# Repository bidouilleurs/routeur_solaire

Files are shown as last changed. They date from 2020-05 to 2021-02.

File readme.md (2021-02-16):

# Réseautonome - Routeur offgrid

## Sommaire
* [Tutoriels videos](#Tutoriels-videos)
* [Parametrage](#Parametrage)
  * [Parametrage pour l algorithme](#Parametrage-pour-l-algorithme)
  * [Fonctionnalites optionnelles du systeme](#Fonctionnalites-optionnelles-du-systeme)
  * [Parametrage le fonctionnement du serveur web](#Parametrage-le-fonctionnement-du-serveur-web)
  * [Parametrage pour le fonctionnement MQTT](#Parametrage-pour-le-fonctionnement-MQTT)
* [Flash sur ESP](#Flash-sur-ESP)
  * [PlatformIO filaire](#PlatformIO-filaire)
  * [PlatformIO OTA](#PlatformIO-OTA)
* [Developpement](#Developpement)

## Tutoriels videos

Fonctionnement

(https://www.youtube.com/watch?v=k4qtnl1ytJM)

Présentation du prototype

(https://www.youtube.com/watch?v=r0o6uWTO2Bw)

Démonstration

(https://www.youtube.com/watch?v=PUMbBfnpi2k)

Envoyer le programme sur l'esp

(https://www.youtube.com/watch?v=kEmMACQ-4ag)

Présentation du serveur web

(https://www.youtube.com/watch?v=cQqW8xrT0VU)

Explication Hardware

(https://www.youtube.com/watch?v=aPKQgpmWH7U)

Assemblage partiel Hardware

(https://www.youtube.com/watch?v=y1rwfJ6BLlo)

Explication de corrections mineures

(https://www.youtube.com/watch?v=yLEv1khMI3Y)

## Parametrage
### Parametrage pour l algorithme
| Champs | Fichier | default |  description |
| --- | :---: |---: |---:|
| zeropince  | settings.h | -100 | valeur mesurer à zéro |
| coeffPince  | settings.h |  0.0294 | Calculer le coefficient |
| coeffTension  | settings.h | 0.0177533 | diviseur de tension |
| seuilDemarrageBatterie  | settings.h | 56 | seuil de mise en marche de la regulation dans le ballon |
| toleranceNegative  | settings.h | 0.5 | autorisation de 500mA négative au moment de la charge complète |
| utilisation2Sorties  | settings.h | false | validation de la sortie 2eme gradateur |
| temperatureBasculementSortie2  | settings.h | 60 | température pour démarrer la regul sur la sortie 2 |
| temperatureRetourSortie1  | settings.h | 45 |température pour rebasculer sur le premier gradateur  |
| relaisStatique  | settings.h | false | Indique si un relais statique est utilisé |
| seuilMarche  | settings.h | 50 | température ou tension de déclenchement du relais |
| seuilArret  | settings.h | 45 | température ou tension d'arret du relais |
| tensionOuTemperature  | settings.h | "V" | Indique si le seuil est en "V"olts ou en "D"egrés|
| correctionTemperature  | settings.h | -2.3 | |
| basculementMode  | settings.h | "T" |  Choix du mode de basculement : T->température, P-> Puissance zero|
| actif  | settings.h | true | permet d'activer ou désactiver le système
| utilisationPinceAC  | settings.h | true | Utilisation d'une Pince pour la mesure AC
| seuilCoupureAC  | settings.h | 0.3 | Seuil de coupure pour la pince AC
| coeffMesureAc  | settings.h | 0.321 | Coeff de mesure de la pince AC

### Fonctionnalites optionnelles du systeme
Les champs décrits ci-dessous permettent d'activer/désactiver certaines options
Ils sont présent dans le fichier settings.h. Si l'option ne vous interesse pas, il faut mettre la ligne en commentaire (commencer la ligne par '//')
Pour activer l'option :
```
#define  EcranOled 
```
Pour **ne pas** activer l'option
```
//#define  EcranOled 
```

| Champs | Description |
| --- | ---: |
| parametrage | A **n**'utiliser **que** pour faire les essais sans les accessoires  |
| MesureTemperature | Permet la lecture de la sonde de dallas température  |
| Pzem04t | utilise un pzem004 pour la mesure de puissance dans le ballon  |
| Sortie2 | Indique la connexion d'un deuxième Triac  |
| WifiMqtt | Permet la connexion Mqtt sur un serveur : récupération et envoie de données pour de la supervision  |
| Ecran_inverse | Permet d'inverser l'écran
| WifiServer | Met à disposition une page web pour visualiser les données du systèmes et modifier les valeurs de l'algorithme |
| EcranOled | Affichage de certaines infos sur un afficheur Oled |
| Simulation | Simulation de données pour des tests, dans le cas ou le système n'est pas branché |
| OTA | Permet la mise à jour par OTA (over the air) |

### Parametrage le fonctionnement du serveur web
Le serveur web permet de faire les régalges depuis une page web. Pour cela, Deux possibités son disponible :
* connecter l'esp au wifi domestic pour y accéder depuis un navigateur web d'un appareil connecté sur le réseau
* Mettre l'ESP en mode point d'accès (SAP) et connecter son smartphone sur le wifi de l'esp (routeur_esp32)

Dans le cas ou la connexion wifi échoue, l'ESP passe automatiquement en mode point d'accès (SAP)

| Champs | Fichier | default |  description |
| --- | :---: |---: |---:|
| ssid  | settings.h | "" |Identifiant "ssid de la  box internet |
| password  | settings.h | "" | Mot de passe de la box internet  |
| SAP  | src.ino | false | force l'ESP en point d'accès (en dehors du réseau domestique -> ssid: "routeur_esp32"; password : "adminesp32" |

### Parametrage pour le fonctionnement MQTT

Le MQTT permet de recevoir les infos de l'ESP sur un broker MQTT, et de piloter le routeur solaire.
Une connexion au wifi est obligatoire (cf. Serveur web)

| Champs | Fichier |  default |  description |
| --- | :---: |---:|---:|
| mqttServer  | settings.h | "192.168.1.28" | ip du serveur mqtt |
| mqttPort  | settings.h |  1883 | port du serveur mqtt |
| mqttUser  | settings.h |  "" | utilisateur mqtt si nécessaire |
| mqttPassword  | settings.h |  "" | mot "de passe mqtt si nécessaire |
| mqttopic  | settings.h | "sensor/solar"  | Récupération Intensite-Tension-Gradateur-Temperature-puissanceMono-rssi |
| mqttopicInput  | settings.h |  "output/solar" | *Pilotage à distance, voir le chapitre de pilotage* |
| mqttopicParam1  | settings.h |  "param/solar1" | Récupération zeropince-coeffPince-coeffTension-seuilTension-toleranceNeg-actif|
| mqttopicParam2  | settings.h | "param/solar2" |Récupération sortie2-sortie2_tempHaut-sortie2_tempBas-temporisation-sortieActive |
| mqttopicParam3  | settings.h | "param/solar3"  | Récupération sortieRelaisTemp-sortieRelaisTens-relaisMax-relaisMin-Forcage_1h-version-seuilCoupureAC-coeffMesureAc|
| mqttopicPzem1  | settings.h |  "sensor/Pzem1" | Récupération pzem infos : Intensite-Tension-Puissance-Energie-Cosf|

Pour piloter l'ESP à distance, il est possible d'envoyer des infos via mqt, sur le topic défini via la variable **mqttopicInput** (par défaut = output/solar)
| message | description |
| --- | ---:|
| rst  |  reboot l'esp
| batX  |  Changement du seuil de démarrage batterie par la valeur X (X est un nombre, ex: bat51)
| negX  |  Changement de la tolérance négative par la valeur X (X est un nombre, ex: neg0.6)
| sthX  |  Changement du seuil de température haute par la valeur X (X est un nombre, ex: sth51)
| stbX  |  Changement du seuil de température basse par la valeur X (X est un nombre, ex: stb51)
| rthX  |  Changement du relais tension haut par la valeur X (X est un nombre, ex: rth51)
| rtbX  |  Changement du relais tension bas par la valeur X (X est un nombre, ex: rtb51)
| sorX  |  Changement de la réception de sortie pour la commande du 2eme gradateur (X=0 ou X=1)
| cmfX  |  Changement de la marche forcée - 1 pour l'activer, 0 pour l'arreter (X=0 ou X=1)
| rmfX  |  Changement du ratio de la marche force, en % (ex : rfm25)
| tmpX  |  Changement du temps de la marche forcée, en minutes (ex: tmp60)
| relX  |  Changement du relais statique X=0 pour désactiver le relais, X=1 pour activer en mode températuren, X=2 pour activer en mode tension
| tmpX  |  Temps de la marche forcée. X minutes.
| temX  |  indique que le ballon est a X degrés. Uniquement dans le cas ou la propriété MesureTemperature n'est pas activée dans le settings

Pour activer / désactiver le routeur complétement, il faut envoyer un message sur le topic **router/activation**
* 1 pour activer
* 0 pour désactiver

## Flash sur ESP

### PlatformIO filaire
#### Installation VSCodium
https://github.com/VSCodium/vscodium/releases

#### Plugin PlatformIO
Depuis vscodium : 
file -> préference -> extension, rechercher et installer platformIO IDE

#### Application
Choisissez l'environnement **env:routeur_solaire**
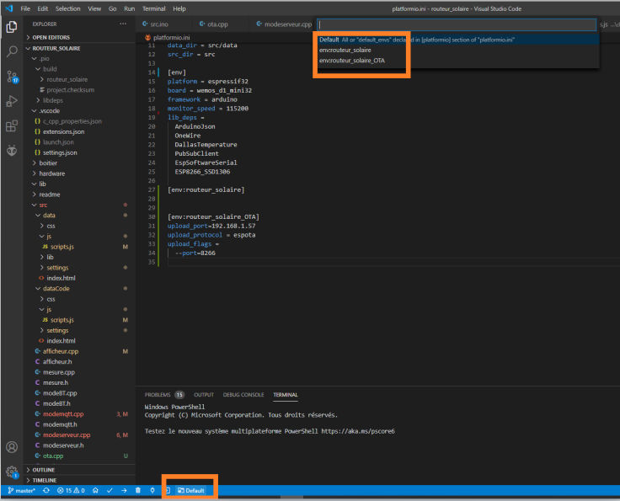
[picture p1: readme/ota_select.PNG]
Ota Select


Selectionner l'onglet plateformio dans le menu latérial (la tete de fourmi), puis déplier les options de l'environnement **env:routeur_solaire**
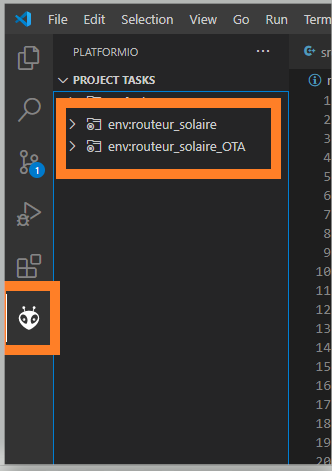
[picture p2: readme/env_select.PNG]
Env Select

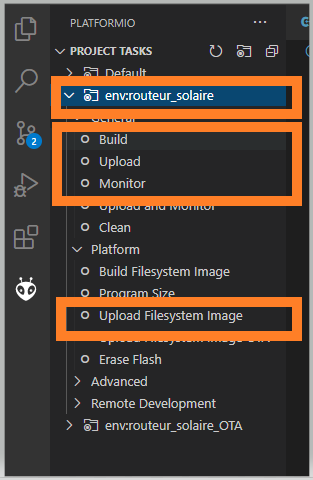
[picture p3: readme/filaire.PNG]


L'option **Build** compile le projet
L'option **upload** permet de flasher l'ESP avec le code compiler
L'option **Monitor** permet de visualiser les logs de l'ESP (infos IP, infos des mesures, ...)
L'option **upload Filesystem Image** permet d'envoyer les fichiers du serveur web

### PlatformIO OTA
**/!\\ Une première installation filaire est nécessaire !**
La mise à jour à distance nécessite que l'ESP soit connecté au réseau.

Dans le fichier plateformio.ini présent à la racine du dossier, il faut renseigner l'adresse IP de l'esp :
```
upload_port=192.168.1.57
```
L'adresse IP de l'ESP est affichée dans les logs, au démarrage de l'ESP (CF section Monitor)
IP OTA

Cliquer sur **Default** puis choisissez **env:routeur_solaire_OTA**
Ota Select

Selectionner l'onglet plateformio dans le menu latérial (la tete de fourmi), puis déplier les options de l'environnement **env:routeur_solaire_OTA**
Env Select
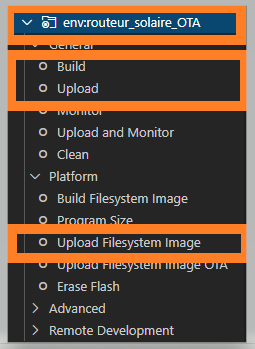
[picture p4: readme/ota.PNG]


Seul les options Build, upload et upload filesystem image sont disponibles
L'option **Build** compile le projet
L'option **upload** permet de flasher l'ESP avec le code compiler via OTA
L'option **upload Filesystem Image** permet d'envoyer les fichiers du serveur web via OTA

## Developpement
Pour changer des fonctionnalités, vous pouvez éditer le code.
Si vous souhaitez éditer le code du serveur web, il faut modifier les fichiers présents dans le dossier "dataCode" puis, une fois les changements effectués, minifier le code dans le dossier "data".
Outils en ligne pour minimifier le code : 
html / css / js : http://minifycode.com/javascript-minifier/
json : https://www.webtoolkitonline.com/json-minifier.html

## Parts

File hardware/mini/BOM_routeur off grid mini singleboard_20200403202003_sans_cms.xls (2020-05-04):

Designator | Quantity | LCSC Part number | Name | Footprint | Manufacturer Part | Manufacturer
P12 | 1 | C182807 | PinceDC | WJ2EDGVC-5.08-4P | EK508V-04P | Dinkle
Q2 | 1 | C9103 | BTA41-600BRG | TOP3-1 | BTA41-600BRG | STMicroelectronics
J1 | 1 | C65114 | Header-Male-2.54_2x3 | HDR-TH_6PIN-V-ROW2-COL3-MALE-PITCH2.54 | Header-Male-2.54_2x3 | BOOMELE
U7 | 1 | C209907 | HILINK 5V 1A | FP_HILINK_5V_1A | HLK-5M05 | HI-LINK
F3 | 1 | C3131 | 5x20 BLX-Atype Fuse holder XC-7 | FUSE-TH_L22.6-W9.0 | 5x20 BLX-Atype Fuse holder XC-7 | XCFuse
U1,U3 | 2 | C395958 | CONN-TH_2P-P9.50_DBT50G-9.5-2P | DBT50G-9.5-2P | DBT50G-9.5-2P | DIBO
J2,J3,J4 | 3 | C182803 | CON_TERMINAL_BLOCK_03-5MM | TERMINAL_BLOCK_3P_5 | ? | Dinkle
P9 | 1 | C128027 | VoltBAT | WJ2EDGVC-5.08-2P | PA001-2P | HIWA
U22 | 1 | C5665 | IDCSC-10 | IDCSC-10-SHAPE | IDCSC-10 | BOOMELE
ESP32_F | 2 | C30867 | ESP32 female header | HDR-TH_20PIN-V-ROW2-COL10-FEMALE-PITCH2.54 | Header-Female-2.54_2x10 | BOOMELE
ESP32_M | 2 | C124359 | ESP32 male header | HDR-TH_20PIN-V-ROW2-COL10-MALE-PITCH2.54 | Header-Male-2.54_2x10 | Ckmtw
U22_F | 1 | C8373 | IDC Connectors 2X5P RoHS | 2X5P | IDCSC-10-F | BOOMELE
JMP1 | 1 | C100114 | Jumper | SIP2 | ? | BOOMELE
FUSE1 | 1 | C142724 | Cartige Fuse 5x20 | 5x20 | 0216002.MXP | Littelfuse
HEAT1 | 1 | C35538 | Heatsink 24x10x100 | 24x10x100 | 24*10*100 Heat Sinks RoHS | XSD

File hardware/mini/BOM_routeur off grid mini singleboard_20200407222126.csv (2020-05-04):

ID | Name | Designator | Footprint | Quantity | Manufacturer Part | Manufacturer | Supplier | Supplier Part | LCSC Assembly
1 | 100nF | C5,C2,C7 | C0805 | 3 | CC0805KRX7R9BB104 | YAGEO | LCSC | C49678 | Yes
2 | MB10S_C2488 | D3 | DIO-BG-SMD_4P-L4.9-W4.0-P2.54-LS7.0-BL | 1 | MB10S | MDD | LCSC | C2488 | Yes
3 | EL357N(B)(TA)-G | U16 | OPTO-SMD-4_L4.4-W4.1-P2.54-LS7.0-TL | 1 | EL357N(B)(TA)-G | EVERLIGHT | LCSC | C6649 | Yes
4 | 1K | R8,R10,R3 | R0805 | 3 | 0805W8F1001T5E | UniOhm | LCSC | C17513 | Yes
5 | PinceDC | P12 | WJ2EDGVC-5.08-4P | 1 | EK508V-04P | Dinkle | LCSC | C182807
6 | DBT50G-9.5-2P | U1,U3 | CONN-TH_2P-P9.50_DBT50G-9.5-2P | 2 | DBT50G-9.5-2P | DIBO | LCSC | C395958
7 | 2.2K | R5 | R0805 | 1 | 0805W8F2201T5E | UniOhm | LCSC | C17520 | Yes
8 | BTA41-600BRG | Q2 | TOP3-1 | 1 | BTA41-600BRG | STMicroelectronics | LCSC | C9103
9 | 20K | R4 | R0805 | 1 | 0805W8F2002T5E | UniOhm | LCSC | C4328 | Yes
10 | AMS1117-3.3 | U2 | SOT-223-3_L6.5-W3.4-P2.30-LS7.0-BR | 1 | AMS1117-3.3 | AMS | LCSC | C6186 | Yes
11 | 330 | R16,R1 | R0805 | 2 | 0805W8F3300T5E | UniOhm | LCSC | C17630 | Yes
12 | Header-Male-2.54_2x3 | J1 | HDR-TH_6PIN-V-ROW2-COL3-MALE-PITCH2.54 | 1 | Header-Male-2.54_2x3 | BOOMELE | LCSC | C65114
13 | HILINK 5V 1A | U7 | FP_HILINK_5V_1A | 1 | HLK-5M05 | HI-LINK | LCSC | C209907
14 | 5x20 BLX-Atype Fuse holder XC-7 | F3 | FUSE-TH_L22.6-W9.0 | 1 | 5x20 BLX-Atype Fuse holder XC-7 | XCFuse | LCSC | C3131
15 | 1nF | C3,C4 | C0805 | 2 | CL21B102KBCNNNC | SAMSUNG | LCSC | C46653 | Yes
16 | KT-0603R | LED1 | LED0603-FD | 1 | KT-0603R | KENTO | LCSC | C2286 | Yes
17 | 100K | R12,R13,R14,R15,R22,R23,R24,R25,R26,R27,R28,R29,R30,R31,R32 | R1206 | 15 | 1206W4F1003T5E | UniOhm | LCSC | C17900 | Yes
18 | CON_TERMINAL_BLOCK_03-5MM | J2,J3,J4 | TERMINAL_BLOCK_3P_5 | 3 | ? |  | LCSC | C182803
19 | 4.7K | R6 | R0805 | 1 | 0805W8F4701T5E | UniOhm | LCSC | C17673 | Yes
20 | 100uF | C1,C6 | CAP-SMD_L3.5-W2.8 | 2 | TAJB107K006RNJ | AVX | LCSC | C16133 | Yes
21 | OR-MOC3021S | U15 | SOP-6_L7.1-W10.1-P2.54-BR | 1 | OR-MOC3021S | Orient | LCSC | C370899 | Yes
22 | 10K | R7,R17 | R0805 | 2 | 0805W8F1002T5E | UniOhm | LCSC | C17414 | Yes
23 | VoltBAT | P9 | WJ2EDGVC-5.08-2P | 1 | PA001-2P | HIWA | LCSC | C128027
24 | ZMM3V3 | D4,D1 | LL-34_L3.5-W1.5-RD | 2 | ZMM3V3 | SEMTECH | LCSC | C8056 | Yes
25 | 1K | R19,R2,R11,R18 | R1206 | 4 | 1206W4F1001T5E | UniOhm | LCSC | C4410 | Yes
26 | Pot 10k | VR1 | SINGLEPOT | 1
27 | ESP32S - Wemos ESP32S | U4 | ESP32-TEST | 1 | ESP32S
28 | IDCSC-10 | U22 | IDCSC-10-SHAPE | 1 | IDCSC-10 |  | LCSC | C5665

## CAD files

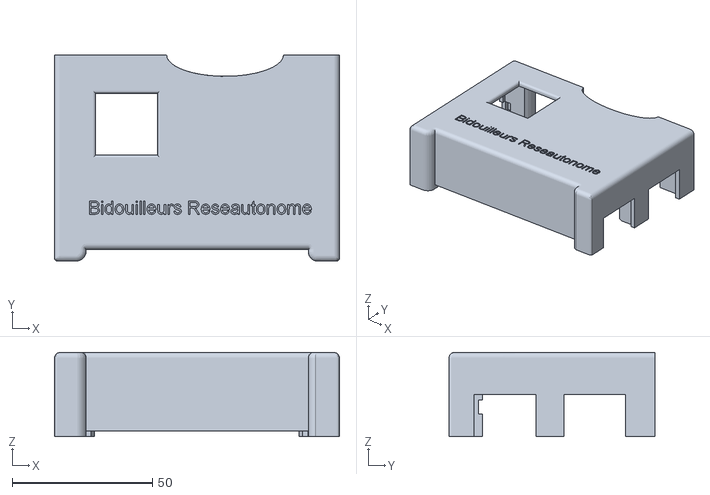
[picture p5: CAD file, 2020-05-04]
boitier/mini/routeurhaut.stl
101.6 x 73.5 x 30.0

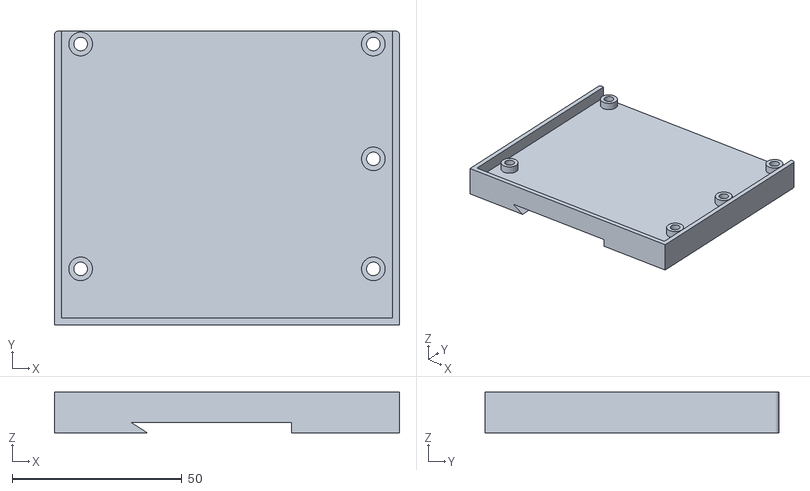
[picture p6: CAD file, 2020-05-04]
boitier/mini/routeurbas.stl
101.6 x 86.5 x 12.0

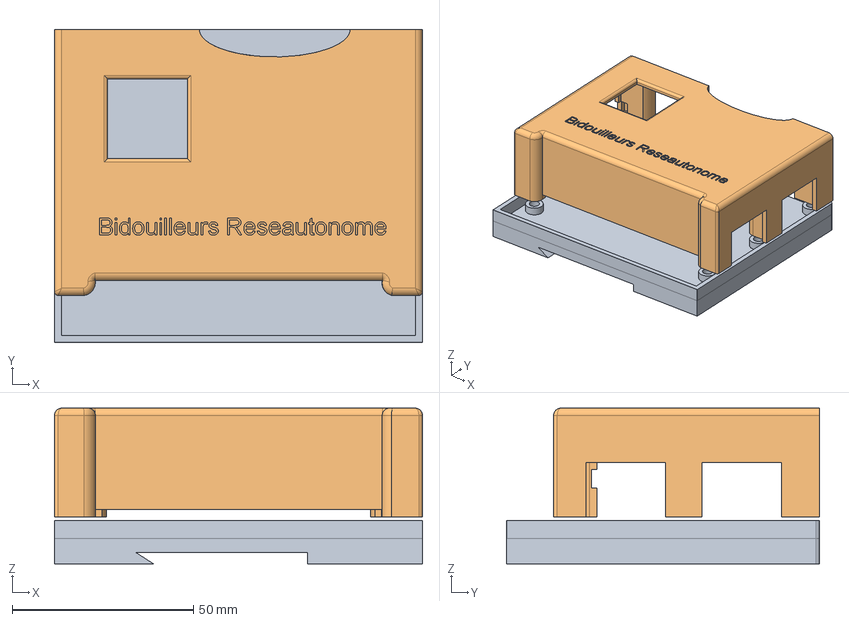
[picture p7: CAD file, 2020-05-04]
boitier/mini/routeur_fond.fcstd
101.6 x 86.5 x 43.0 mm

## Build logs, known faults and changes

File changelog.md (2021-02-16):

# Version 1.5
- Ajout d'un paramètre indiquant l'utilisation d'une pince AC, activable par le serveur web
- Possibilité de forcer le SAP depuis le serveur web
- Modification de certaines infos MQTT : ajout RSSI et mesureAC dans sensor/solar, et version-seuilCoupureAC-coeffMesureAc dans param/solar3
- Ajout du RSSI dans l'onglet communication du serveur web
- La page web indique la présence d'une nouvelle version via un message temporaire
- Meilleure gestion du passage SAP / Wifi
- Ajout d'un paramètre permettant d'inverser l'écran OLED présent dans settings.h
- Stockage des lib externes pour éviter tout problème

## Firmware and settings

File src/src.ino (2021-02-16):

//**************************************************************/
// L'équipe de bidouilleurs discord reseautonome vous présente
// la réalisation d'un gradateur pour chauffe-eau en off grid
// gradateur synchronisé sur la production photovoltaique
// sans tirage sur les batteries pour utiliser le surplus dans
// un ballon d'eau chaude
//**************************************************************/

const char *version_soft = "Version 1.5";

//**************************************************************/
// Initialisation
//**************************************************************/
#include "settings.h"
struct param routeur;
const int pinTriac = 27;         // GPIO27 triac
const int pinPince = 32;         // GPIO32   pince effet hall
const int zeroc = 33;            // GPIO33  passage par zéro de la sinusoide
const int pinPinceRef = 34;      // GPIO34   pince effet hall ref 2.5V
const int pinPotentiometre = 35; // GPIO35   potentiomètre
const int pinTension = 36;       // GPIO36   capteur tension
const int pinTemp = 23;          // GPIO23  capteurTempérature
const int pinSortie2 = 13;       // pin13 pour  2eme "gradateur
const int pinRelais = 19;        // Pin19 pour sortie relais
const int pinPinceAC = 39;       // GPIO39 pince AC
bool marcheForcee = false;
short int marcheForceePercentage = 25;
short int sortieActive = 1;
unsigned long temporisation = 60;
float intensiteBatterie = 0;
float capteurTension = 0;
int puissanceGradateur = 0;
float temperatureEauChaude = 0;
float puissanceDeChauffe = 0;
bool etatRelaisStatique = false;
bool modeparametrage = false;

int resetEsp = 0;
int testwifi = 0;
int choixSortie = 0;
int paramchange = 0;
bool SAP = false;
bool MQTT = false;
char traceurserie[50];
#ifdef Pzem04t
float Pzem_i = 0;

float Pzem_U = 0;
float Pzem_P = 0;
float Pzem_W = 0;
#endif
/**********************************************/
/********** déclaration des librairiess *******/
/**********************************************/
#include "triac.h"

#include "communication.h"

#ifdef OTA
#include "ota.h"
#endif
#ifdef EEprom
#include "prgEEprom.h"
#endif

#ifdef EcranOled
#include "afficheur.h"
#endif

//#define simulation // utiliser pour faire les essais sans les accessoires
#ifdef simulation
#include "simulation.h"
#endif

#include "mesure.h"
#include "regulation.h"
int iloop = 0; // pour le parametrage par niveau
extern int calPuis;
float mesureAc = 0;
/***************************************/
/******** Programme principal   ********/
/***************************************/
void setup()
{
  Serial.begin(115200);

  pinMode(pinTriac, OUTPUT);
  digitalWrite(pinTriac, LOW); // mise à zéro du triac au démarrage
  pinMode(pinSortie2, OUTPUT);
  digitalWrite(pinSortie2, LOW); // mise à zéro du triac de la sortie 2
  pinMode(pinRelais, OUTPUT);
  digitalWrite(pinRelais, LOW); // mise à zéro du relais statique
  pinMode(pinTemp, INPUT);
  pinMode(pinTension, INPUT);
  pinMode(pinPotentiometre, INPUT);
  pinMode(pinPince, INPUT);
  pinMode(pinPinceRef, INPUT);
  RACommunication.print(1, "", true);
  RACommunication.print(1, "definition ok ", true);
  RACommunication.print(1, version_soft, true);
  RACommunication.print(1, "", true);

#ifdef EcranOled
  RAAfficheur.setup();
#endif

#ifdef EEprom
  RAPrgEEprom.setup();
#endif

  delay(500);
  marcheForcee = false; // mode forcé retirer au démarrage
  marcheForceePercentage = 0;
  temporisation = 0;

#if defined WifiMqtt || defined WifiServer
  RACommunication.setup(version_soft);
#endif

#ifdef OTA
  RAOTA.begin();
#endif

#ifdef EcranOled
  RAAfficheur.setup();
#endif

#ifdef MesureTemperature
  RAMesure.setup();
#endif

#ifdef Pzem04t
  Serial2.begin(9600, SERIAL_8N1, RXD2, TXD2); // redefinition des broches du serial2
#endif

#ifdef parametrage
  modeparametrage = true;
#endif

  delay(500);
  RATriac.watchdog(0);       // initialise le watchdog
  RATriac.start_interrupt(); // demarre l'interruption de zerocrossing et du timer pour la gestion du triac
}

void loop()
{
#ifdef OTA
  RAOTA.loop();
#endif

  RATriac.watchdog(1);                  //chien de garde à 4secondes dans timer0
  RAMesure.mesurePinceTension(700, 20); // mesure le courant et la tension avec 2 boucles de filtrage (700,20)
  if (routeur.utilisationPinceAC)
  {
    mesureAc = RAMesure.mesurePinceAC(pinPinceAC, routeur.coeffMesureAc, false);
  }

#ifdef simulation
  if (!modeparametrage)
    RASimulation.imageMesure(0); // permet de faire des essais sans matériel
  RACommunication.print(1, "Mode simulation", true);
#endif

  if (!modeparametrage)
  {
    RAMesure.mesureTemperature(); // mesure la temperature sur le ds18b20
    RAMesure.mesure_puissance();  // mesure la puissance sur le pzem004t

    int dev = RARegulation.mesureDerive(intensiteBatterie, 0.2); // donne 1 si ça dépasse l'encadrement haut et -1 si c'est en dessous de l'encadrement (Pince,0.2)

    if (mesureAc < routeur.seuilCoupureAC)
    {

      if (routeur.actif)
      {
        puissanceGradateur = RARegulation.regulGrad(dev); // calcule l'augmentation ou diminution du courant dans le ballon en fonction de la deviation
      }
      else
      {
        puissanceGradateur = 0;
      }
      RARegulation.pilotage(); // pilotage à distance
    }

    else
    {
      calPuis = 0;
      puissanceGradateur = 0;
    }
  }

  if (modeparametrage)
  {
    //    int potar = map(analogRead(pinPotentiometre), 0, 4095, 0, 1000); // controle provisoire avec pot
    iloop++;
    if (iloop < 10)
      puissanceGradateur = 1;
    else if (iloop < 20)
      puissanceGradateur = 100;
    else if (iloop < 30)
      puissanceGradateur = 200;
    else if (iloop < 40)
      puissanceGradateur = 400;
    else if (iloop < 50)
      puissanceGradateur = 600;
    else if (iloop < 60)
      puissanceGradateur = 1000;
    else
      iloop = 0;
    /*   if (potar>10) puissanceGradateur=potar;
         else  if (potar<2) puissanceGradateur=0;
                      else puissanceGradateur=1; // priorité au potensiometre                    // priorité au potensiometre
      */
    char paramLog[50];
    sprintf(paramLog, "Courant %2.2f, Tension %2.2f, Gradateur %d", intensiteBatterie, capteurTension, puissanceGradateur);
    RACommunication.print(1, paramLog, true);

    delay(200);
  }

  // affichage traceur serie
  float c = puissanceGradateur;

  sprintf(traceurserie, "%2.2f,%d,%2.2f,%2.2f,%2.2f,%2.2f,%2.2f",
          c / 100,
          devlente * 2,
          intensiteBatterie,
          routeur.seuilDemarrageBatterie / 5,
          -routeur.toleranceNegative,
          mesureAc,
          capteurTension / 5);
  RACommunication.print(1, traceurserie, true);
  //  Serial.print("zero");  Serial.println(routeur.zeropince);

#ifdef EcranOled
  RAAfficheur.affichage_oled(); // affichage de lcd
#endif

#if defined WifiMqtt || defined WifiServer
  RACommunication.loop();
#endif

#ifdef EEprom

  if (resetEsp == 1)
  {
    RATriac.stop_interrupt();
    RAPrgEEprom.close_param();
    delay(5000);
  }
#endif

  if (resetEsp == 1)
  {

    RACommunication.print(1, "Restart !", true);
    ESP.restart(); // redemarrage"
  }
}

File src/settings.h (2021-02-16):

#ifndef RA_SETTINGS_H
#define RA_SETTINGS_H
/**********************************************/
/********** Liste des options possibles ******/
/********************************************/
//#define parametrage // utiliser pour faire les essais sans les accessoires

//**** options MINI ****
#define EcranOled         // si pas d'écran oled      installer librairie heltec dev board
#define MesureTemperature // capteur DS18B20       installer librairie dallas temperature
#define WifiServer        // affiche les mesures dans une page html crée un point d'accès si pas de reseau
#define WifiMqtt          // mettre en commentaire si pas de réseau       installer librairie ArduinoJson et PubSubClient
#define OTA               // permet la mise à jour par OTA (over the air)
// #define Ecran_inverse

//**** options MAXI  ****
#define Pzem04t // utilise un pzem004 pour la mesure de puissance dans le ballon  inclure  https://github.com/mandulaj/PZEM-004T-v30
#define Sortie2 // utilise un 2eme triac
#define F50HZ   // Frequence du reseau 50Hz ou 60Hz non testé

const int VERBOSE = 1; // 0 pour rien , 1 pour info traceur serie, 2 pour error, 3 pour debug
struct param
{
  float zeropince = -20.84;                 // valeur mesurer à zéro (2) 2819 2818.5
  float coeffPince = 0.02475;               // Calculer le coefficient (4)0.14 0.210
  float coeffTension = 0.02008;             // diviseur de tension
  float seuilDemarrageBatterie = 57.20;     // seuil de mise en marche de la regulation dans le ballon
  float toleranceNegative = 0.8;            // autorisation de 300mA négative au moment de la charge complète
  bool utilisation2Sorties = false;         // validation de la sortie 2eme gradateur
  float temperatureBasculementSortie2 = 60; // température pour démarrer la regul sur la sortie 2
  float temperatureRetourSortie1 = 45;      // température pour rebasculer sur le premier gradateur
  bool relaisStatique = false;              // Indique si un relais statique est utilisé
  float seuilMarche = 50;                   // température ou tension de déclenchement du relais
  float seuilArret = 45;                    // température ou tension de déclenchement du relais
  char tensionOuTemperature[2] = "V";       // Indique si le seuil est en Volts ou en Degrés
  char ssid[30] = "Bbox-xxxxxxx";           // ssid de la box internet
  char password[50] = "6557D4EFxxxxxxxx";     // mot de passe
                                            // en mode serveur l'ip est 192.168.4.1'
                                            // ssid , "routeur_esp32"
                                            // password , "adminesp32"
  char mqttServer[30] = "192.168.1.18";
  short int mqttPort = 1883;
  char mqttUser[30] = "mosquitto";
  char mqttPassword[50] = "!*mosquitto*!";
  char mqttopic[30] = "sensor/solar";
  char mqttopicInput[30] = "output/solar";
  char mqttopicParam1[30] = "param/solar1";
  char mqttopicParam2[30] = "param/solar2";
  char mqttopicParam3[30] = "param/solar3";
  char mqttopicPzem1[30] = "sensor/Pzem1";
  float correctionTemperature = -2.3;
  char basculementMode[2] = "T"; // Choix du mode de basculement : T->température, P-> Puissance zero
  bool actif = true;
  float seuilCoupureAC = 0.3;      // Seuil de coupure pour la pince AC
  float coeffMesureAc = 0.321;     // Coeff de mesure de la pince AC
  bool utilisationPinceAC = false; // Utilisation d'une Pince pour la mesure AC
  bool utilisationSAP = false;     // Utilisation du SAP uniquement
};
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

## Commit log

2020-05-02 Passage en SAP si attente trop longue pour la connexion WiFi
2020-05-03 correction sur le ré affichage de la page de résumé après plus de 30s
2020-05-04 ajout d'un bouton pour valider sans redémarrer + correction bug changement mode de basculement + amélioration du code
    [afficheur.cpp, regulation.cpp, settings.h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]
2020-05-04 ajout de la doc boitier et hardware
    [BOM_routeur off grid mini singleboard_20200403202003_sans_cms.xls, BOM_routeur off grid mini singleboard_20200407222126.csv, PickAndPlace_PCB_2020-04-02 19_31_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]
2020-05-06 ajout de fichiers hardware + corrections diverses
    [afficheur.cpp, src.ino]
2020-05-22 Update platformio.ini
    Changement nom de la variable env:
2020-05-30 Modif de regulation
    Simplification de la régulation et adaptation aux différents types de batteries.
2020-06-26 correction régulation + chiffre négatif avec clavier samsung + page d'action de reboot et reset de l'esp
    [regulation.cpp, settings.h, src.ino]
2020-08-19 fix problèmes de commutations de sorties triacs et relais statique
    [mesure.cpp, regulation.cpp, settings.h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]
2020-09-01 Correction d'un bug dans la fonction marche forcée
    [regulation.cpp]
2020-09-07 fix probleme avec la marche forcée
    [src.ino]
2020-12-12 ajout possibilité d'activer/desactiver le systeme par mqtt et serveur web + possibilité de MAJ par OTA
2020-12-13 montée de version
2021-01-10 ajout de trame mqtt permettant de mieux piloter le routeur + possibiité de mettre en arret le systeme
2021-01-18 Modification de la librairie de l'ecran OLED
